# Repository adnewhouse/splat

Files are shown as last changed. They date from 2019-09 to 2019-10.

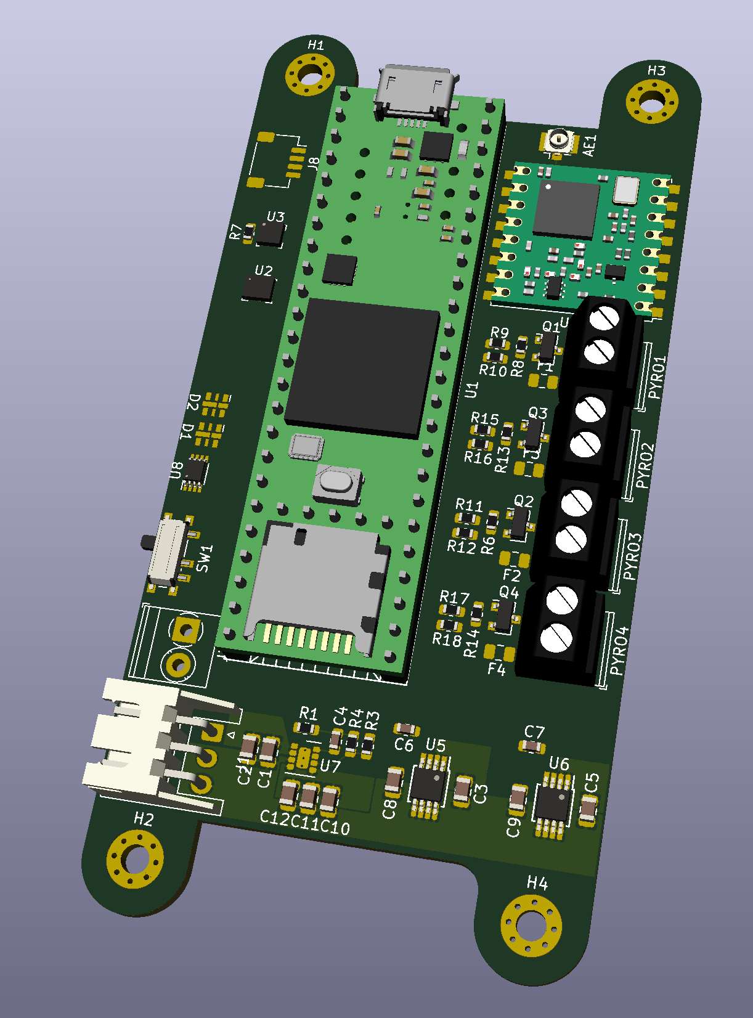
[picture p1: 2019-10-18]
render.png

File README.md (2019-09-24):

# Splat Rocket Flight Computer

Splat is a simple data logger/flight computer for hobby-class rockets. 

Current featureset includes:
- Teensy 3.6 for main CPU
- BMP380 Barometer
- 4x Pyro output channels (with continuity check and fire verification)
- Support for external GPS module
- Buzzer
- Dual RGB LEDs
- 3x Servo channels for TVC
- LoRa Radio Module for telemetry and real time data
- ISM330DLC 6-axis IMU
- MicroSD card for data logging
- SPI flash for faster data rate logging

# Project Status

Splat is still in the stages of schematic capture

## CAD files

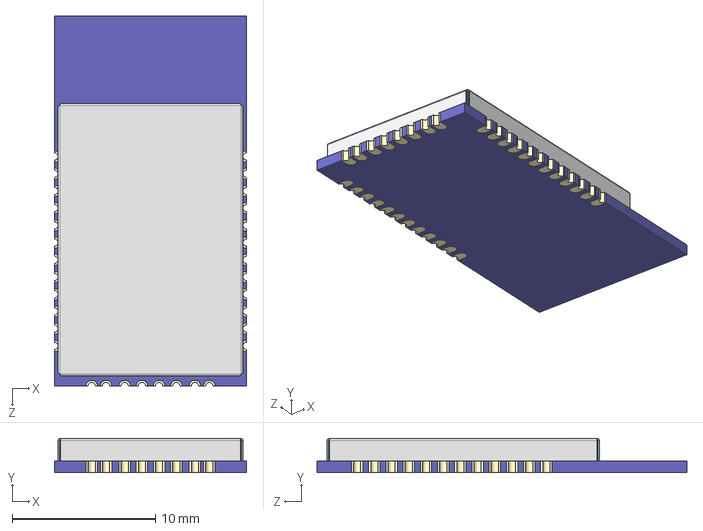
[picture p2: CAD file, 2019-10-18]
3d/RM--3DModel-STEP-56544.STEP
13.4 x 2.40 x 25.8 mm

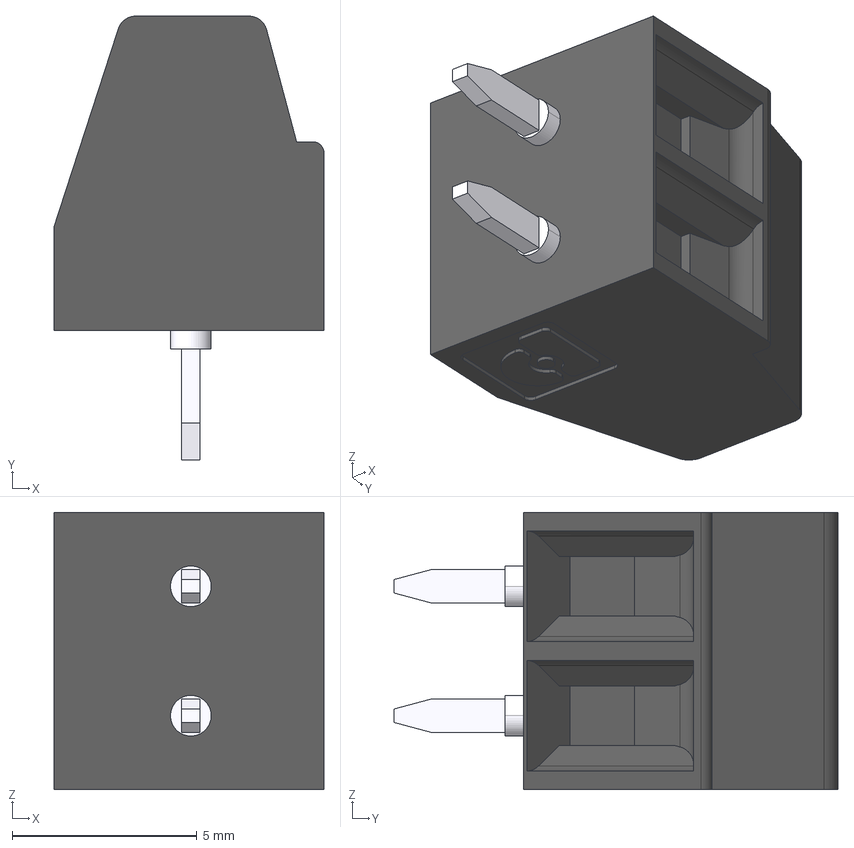
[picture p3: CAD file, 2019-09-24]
3d/pxc_1985807_02_MKDS-1-2-3-5-HT-BK_3D.stp
7.30 x 12.0 x 7.50 mm

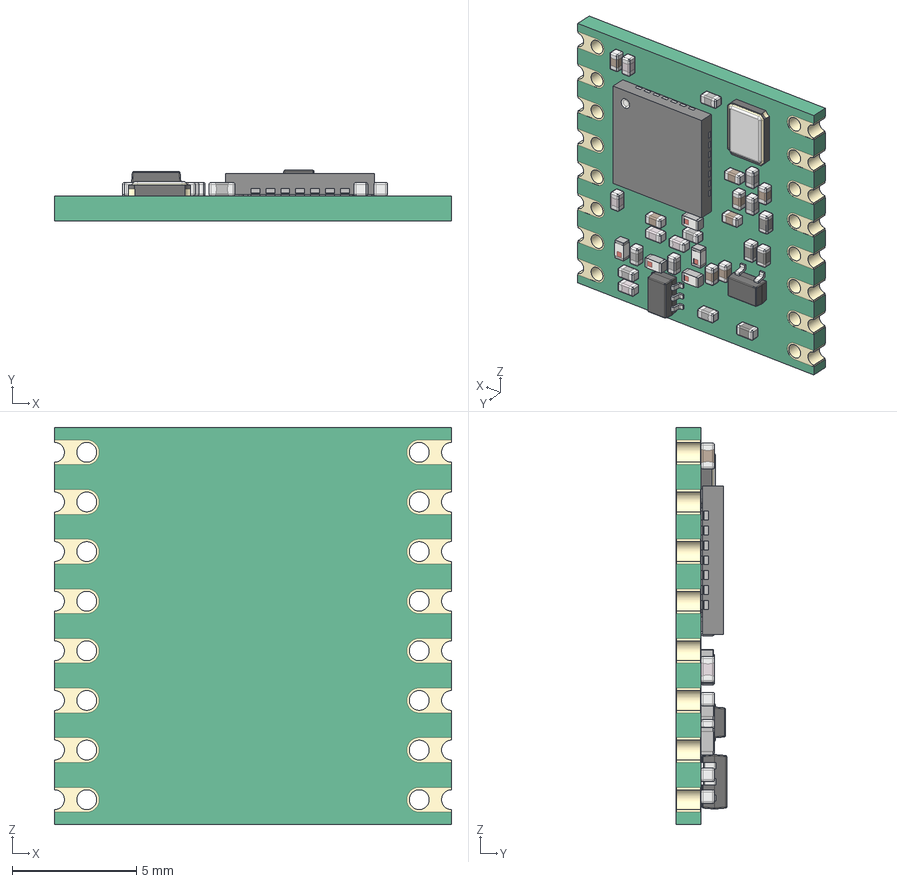
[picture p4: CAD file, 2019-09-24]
3d/RFM95 LoRa v15.step
16.0 x 2.04 x 16.0 mm
QFN 28
SMD Crystal
CAP 0403 x 8
CAP Ceramic 0403 x 8
Res 0403 x 4
CAP ML 0403 x 5
SOT-323
Inductor SMD 0403 x 5
SOT-363

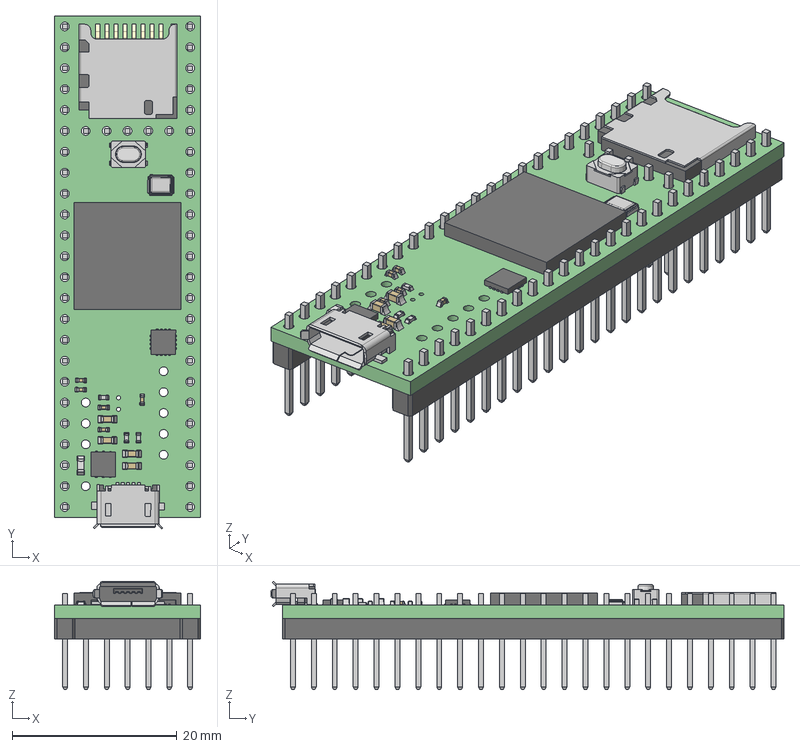
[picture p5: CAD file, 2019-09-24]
3d/Teensy 3.5 - 3.6.step
17.8 x 62.4 x 13.1 mm
micro_usb_plastic (1)
micro_usb_shell (1)
package
lead (1)
lead (2)
diode_0402 v1 x 4
cap0603_03 v3 x 5
cap0402 v2 (1) x 2
smt_led_0805 v2
cap0402 v2 x 5
resistor_0603 v3
Full Board
lead
Base
Case

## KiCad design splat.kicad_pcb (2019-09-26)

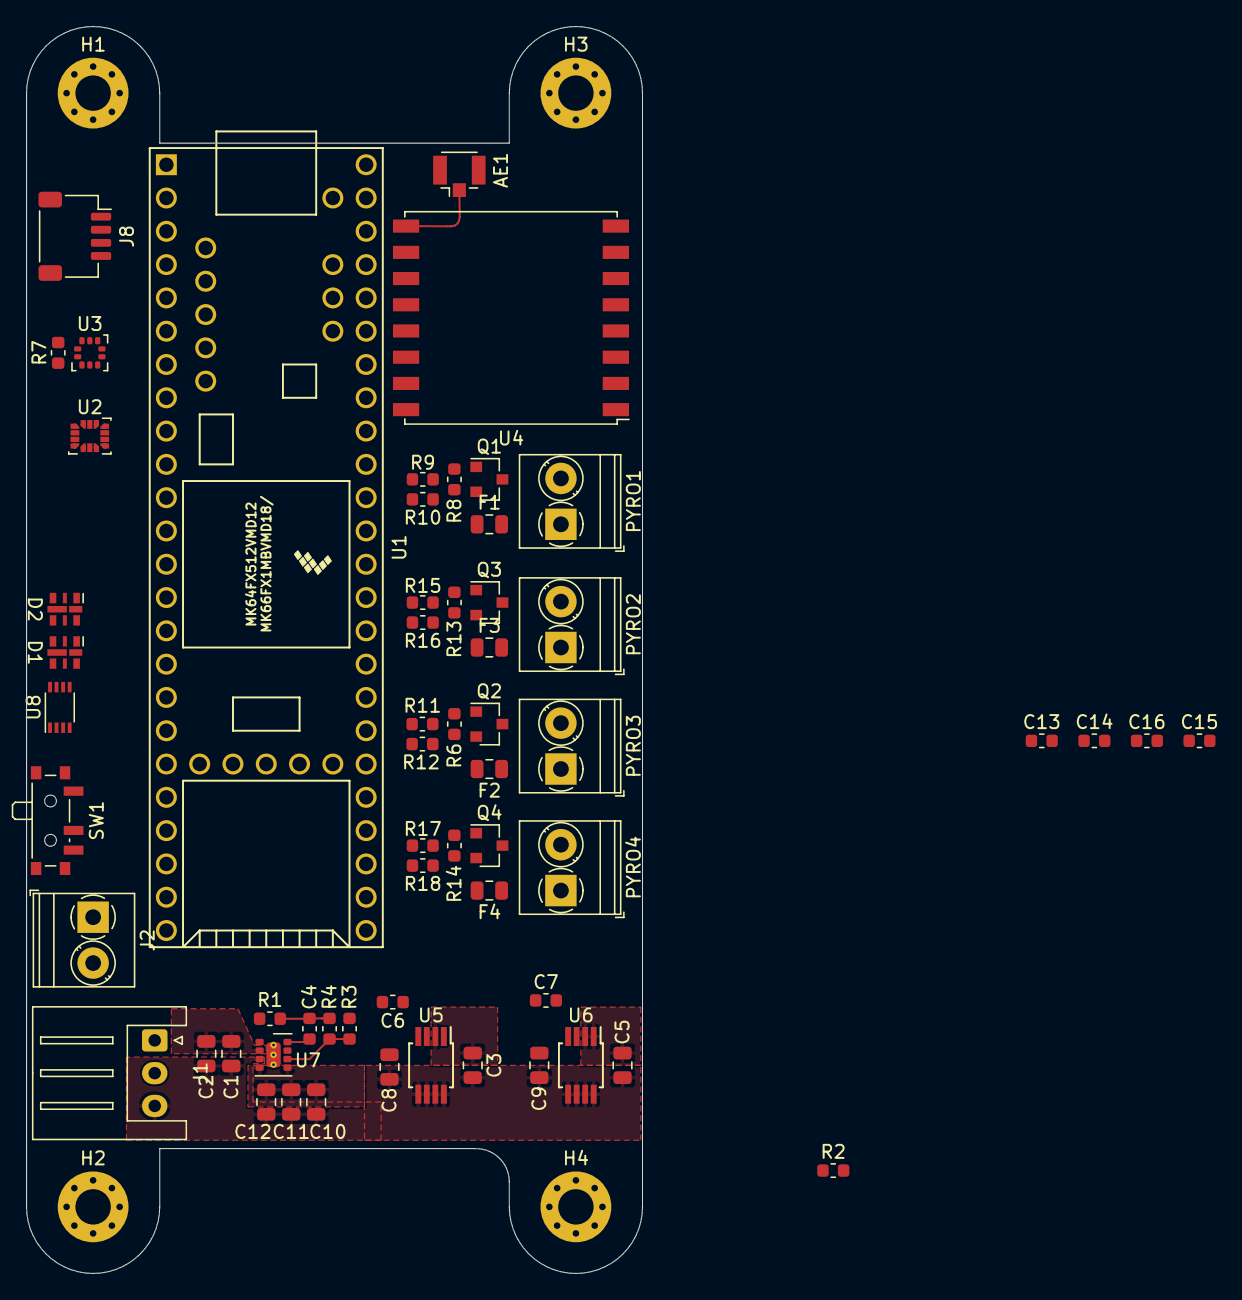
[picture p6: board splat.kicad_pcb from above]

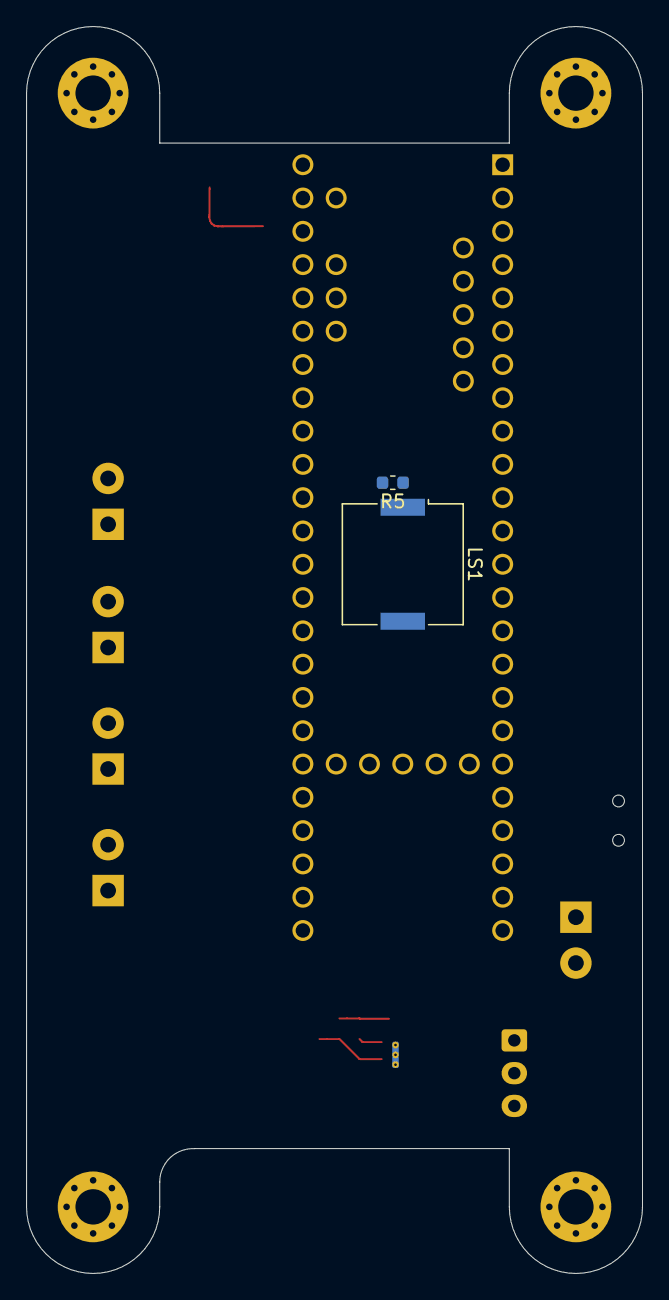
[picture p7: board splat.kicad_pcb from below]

Board: 4 copper layers, 47.0 x 95.1 mm, 66 parts (2 on the bottom side), 49 nets.

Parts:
AE1: Antenna_Shield; U.FL_Hirose_U.FL-R-SMT-1_Vertical
C1, C2: 10uF; C_0805_2012Metric
C3, C5: 1uF; C_0805_2012Metric
C4: 430pF; C_0603_1608Metric
C6, C7: 680pF; C_0603_1608Metric
C8, C9: 2.2uF; C_0805_2012Metric
C10, C11, C12: 22uF; C_0805_2012Metric
C13, C15: 100nF; C_0603_1608Metric
C14, C16: 1uF; C_0603_1608Metric
D1, D2: APA102-2020; LED-APA102-2020
F1, F2, F3, F4: Polyfuse; Fuse_0805_2012Metric
H1, H2, H3, H4: MountingHole_Pad; MountingHole_2.7mm_Pad_Via
J1: BATT; JST_XH_S3B-XH-A_1x03_P2.50mm_Horizontal
J2: EXT_SW; TerminalBlock_Phoenix_PT-1,5-2-3.5-H_1x02_P3.50mm_Horizontal
J4: PYRO1; TerminalBlock_Phoenix_PT-1,5-2-3.5-H_1x02_P3.50mm_Horizontal
J5: PYRO3; TerminalBlock_Phoenix_PT-1,5-2-3.5-H_1x02_P3.50mm_Horizontal
J6: PYRO2; TerminalBlock_Phoenix_PT-1,5-2-3.5-H_1x02_P3.50mm_Horizontal
J7: PYRO4; TerminalBlock_Phoenix_PT-1,5-2-3.5-H_1x02_P3.50mm_Horizontal
J8: Conn_01x04; JST_SH_SM04B-SRSS-TB_1x04-1MP_P1.00mm_Horizontal
LS1: Speaker_Crystal; Buzzer_Murata_PKMCS0909E4000-R1
Q1, Q2, Q3, Q4: NTR4501NT1G; SOT-23
R1, R2, R4, R10, R12, R16, R18: 100K; R_0603_1608Metric
R3: 523K; R_0603_1608Metric
R5: 1K; R_0603_1608Metric
R6, R7, R8, R13, R14: 10K; R_0603_1608Metric
R9, R11, R15, R17: 300K; R_0603_1608Metric
SW1: PWR; SW_SPDT_PCM12
U1: TEENSY3.6; Teensy35_36
U2: ISM330DLC; LGA-14_3x2.5mm_P0.5mm_LayoutBorder3x4y
U3: BMP380; ST_HLGA-10_2.5x2.5mm_P0.6mm_LayoutBorder3x2y
U4: RFM96W-433S2; HOPERF_RFM9XW_SMD
U5, U6: MIC5219-3.3YMM; MSOP-8_3x3mm_P0.65mm
U7: TPS82140; Texas_SIL0008D_MicroSiP-8-1EP_2.8x3mm_P0.65mm_EP1.1x1.9mm_T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
U8: 74LVC2T45DC; VSSOP-8_2.3x2mm_P0.5mm

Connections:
+3V3: C9.1, J8.1, U4.13, U6.3, U8.1
+BATT: C1.1, C2.1, C3.1, C5.1, F1.1, F2.1, F3.1, F4.1, SW1.1, U5.2, U6.1, U6.2, U7.2
/3V3_AUX: C8.1, C13.1, C14.1, C15.1, C16.1, R7.1, U2.5, U2.8, U3.1, U3.10, U5.3
/3V3_AUX_EN: R2.1, U5.1
/5V_EN: R1.1, U7.1
/5V_SERVO: C10.1, C11.1, C12.1, D1.1, D2.1, R3.1, U7.4, U7.5, U8.8
/BEEPER: LS1.1, R5.1
/BMP_INT: R7.2, U1.36, U3.7
/CS_RF: U1.12, U4.5
/IMU_INT1: U1.44, U2.4
/IMU_INT2: U1.43, U2.9
/MISO_0: U1.14, U4.2
/MOSI_0: U1.13, U4.3
/PYRO1_EN: Q1.1, R8.1, U1.2
/PYRO1_SENSE: R9.2, R10.1, U1.42
/PYRO2_EN: Q3.1, R13.1, U1.3
/PYRO2_SENSE: R15.2, R16.1, U1.41
/PYRO3_EN: Q2.1, R6.1, U1.4
/PYRO3_SENSE: R11.2, R12.1, U1.38
/PYRO4_EN: Q4.1, R14.1, U1.5
/PYRO4_SENSE: R17.2, R18.1, U1.37
/RF_DIO0: U1.57, U4.14
/RF_DIO1: U1.56, U4.15
/RF_DIO2: U1.50, U4.16
/RF_DIO3: U1.49, U4.11
/RF_DIO4: U1.48, U4.12
/RF_DIO5: U1.47, U4.7
/RXD_GPS: J8.3, U1.19
/TXD_GPS: J8.2, U1.18
GND: AE1.2, C1.2, C2.2, C3.2, C4.2, C5.2, C6.2, C7.2, C8.2, C9.2, C10.2, C11.2, C12.2, C13.2, C14.2, C15.2, C16.2, D1.6, D2.6, J1.3, J8.4, LS1.2, Q1.2, Q2.2, Q3.2, Q4.2, R1.2, R2.2, R4.2, R5.2, R6.2, R8.2, R10.2, R12.2, R13.2, R14.2, R16.2, R18.2, U1.1, U1.27, U1.39, U1.52, U2.6, U2.7, U3.3, U3.8, U3.9, U4.1, U4.8, U4.10, U5.5, U5.6, U5.7, U5.8, U6.5, U6.6, U6.7, U6.8, U7.3, U7.9, U8.4
unnamed: AE1.1, U4.9
unnamed: C4.1, U7.8
unnamed: C6.1, U5.4
unnamed: C7.1, U6.4
unnamed: D1.2, D2.5
unnamed: D1.3, D2.4
unnamed: D1.4, U8.7
unnamed: D1.5, U8.6
unnamed: F1.2, J4.1
unnamed: F2.2, J5.1
unnamed: F3.2, J6.1
unnamed: F4.2, J7.1
unnamed: J1.1, J2.1
unnamed: J2.2, SW1.2
unnamed: J4.2, Q1.3, R9.1
unnamed: J5.2, Q2.3, R11.1
unnamed: J6.2, Q3.3, R15.1
unnamed: J7.2, Q4.3, R17.1
unnamed: R3.2, R4.1, U7.6

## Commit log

2019-09-21 add kicad files
    [pyro.sch, regulator.sch, splat.kicad_pcb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]
2019-09-21 Add pyro sense
    [pyro.sch, splat.sch]
2019-09-24 Add teensy 3.6, add IMU, start connecting important nets
    [splat.kicad_pcb, splat.sch]
2019-09-24 Start layout, add 3d files
    [RFM95 LoRa v15.step, Teensy 3.5 - 3.6.step, pxc_1985807_02_MKDS-1-2-3-5-HT-BK_3D.stp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]
2019-09-26 Layout and servo connectors
    [splat.kicad_pcb, splat.sch]
2019-10-18 Add render
    [RM--3DModel-STEP-56544.STEP, splat.sch]
